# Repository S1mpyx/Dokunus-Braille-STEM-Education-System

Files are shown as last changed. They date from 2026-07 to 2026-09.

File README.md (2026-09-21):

# 📚 Dokunuş – Dijital İnteraktif Kabartma Yazı Eğitim Seti

> **TEKNOFEST 2026 Projesi**  
> **Synapse Takımı**

---

# 👋 Synapse Takımı Hakkında

Merhaba!

Biz **Synapse Takımı** olarak teknolojiyi toplumsal faydaya dönüştürmeyi hedefleyen bir öğrenci ekibiyiz.

Bu proje, görme engelli bireylerin Braille (Kabartma Yazı) eğitimini daha erişilebilir, bağımsız ve ekonomik hale getirmek amacıyla geliştirilmiştir.

Elektronik, yazılım ve üç boyutlu tasarım alanlarını bir araya getirerek öğrencilerin öğretmen veya veli desteğine daha az ihtiyaç duyacağı, sesli geri bildirim sağlayan interaktif bir eğitim sistemi tasarladık.

Amacımız yalnızca bir prototip geliştirmek değil; eğitimde fırsat eşitliğine katkı sağlayabilecek, geliştirilebilir ve ticarileştirilebilir yerli bir ürün ortaya koymaktır.

---

# 👥 Takımımız

## 👨‍💻 Yiğit Dağlı

- Elektronik sistem tasarımı
- Arduino programlama
- Devre kurulumu
- RFID sisteminin geliştirilmesi
- 3B modelleme (Blender)
- Mekanik tasarım
- Prototip üretimi
- Donanım testleri

---

## 👨‍💻 Alperen Arda

**Takım Kaptanı**

- Literatür araştırması
- Yazılım geliştirme
- Ses kayıtlarının hazırlanması
- SD kart içeriklerinin oluşturulması
- Proje dokümantasyonu
- Sunum hazırlanması

---

## 👩‍🏫 Danışman Öğretmen

**Ceren Gezer**

Proje süreci boyunca teknik, akademik ve organizasyonel konularda ekibimize rehberlik etmiştir.

---

# 📖 Proje Hakkında

Dokunuş, görme engelli öğrencilerin Braille alfabesini ve temel sayıları daha kolay öğrenebilmesi amacıyla geliştirilmiş interaktif bir eğitim setidir.

Mevcut eğitim sürecinde öğrenciler çoğu zaman öğretmen veya aile desteğine ihtiyaç duymaktadır. Ayrıca piyasada bulunan elektronik eğitim cihazlarının büyük bölümü ithal olup oldukça yüksek maliyetlidir.

Dokunuş, öğrencinin yaptığı çalışmayı anında değerlendirerek doğru veya yanlış olduğuna dair sesli geri bildirim verir. Böylece öğrenci istediği zaman kendi başına tekrar yapabilir.

---

# 🎯 Projenin Amacı

- Görme engelli öğrencilerin bağımsız öğrenmesini desteklemek
- Braille eğitimini daha erişilebilir hale getirmek
- Öğretmen ve aile üzerindeki yükü azaltmak
- Yerli ve düşük maliyetli bir eğitim sistemi geliştirmek
- Eğitimde fırsat eşitliğine katkı sağlamak


---

# ❓ Çözülen Problem

Braille öğrenme süreci;

- Yoğun tekrar gerektirir.
- Sürekli eğitmen desteğine ihtiyaç duyabilir.
- Öğrenci yaptığı çalışmanın doğru olup olmadığını anında öğrenemeyebilir.
- Elektronik eğitim cihazları yüksek maliyetlidir.

Dokunuş bu problemlere düşük maliyetli ve taşınabilir bir çözüm sunmaktadır.

---

# ⚙️ Sistem Nasıl Çalışır?

1. Öğrenci çalışma modunu seçer.
2. Braille küplerini RFID okuyucular üzerine yerleştirir.
3. RFID etiketleri algılanır.
4. Arduino doğru dizilimi kontrol eder.
5. DFPlayer Mini üzerinden sesli geri bildirim verilir.
6. Öğrenci doğru cevaba ulaşıncaya kadar çalışmaya devam eder.

---

# 📚 Çalışma Modları

## 🔹 Harf Öğrenme Modu

Küp okutulduğunda;

- Harf okunur.
- O harfle başlayan bir hece söylenir.
- O harfle başlayan bir kelime söylenir.

---

## 🔹 Hece Testi

Sistem rastgele bir hece seçer.

Öğrenci doğru harfleri sıralamaya çalışır.

Yanlış cevaplarda doğru dizilime ulaşılıncaya kadar aynı soru tekrar edilir.

---

## 🔹 Sayı Testi

Sistem rastgele üç basamağa kadar sayı oluşturur.

Öğrenci doğru rakamları sıralar.

Doğru cevap sesli olarak onaylanır.

---

# 🛠️ Kullanılan Donanımlar

- Arduino Uno
- 3 × MFRC522 RFID Modülü
- DFPlayer Mini
- Hoparlör
- Push Button
- NFC/RFID Etiketleri
- AMS1117 Voltaj Regülatörü
- Kondansatörler
- 3B Baskı Parçaları

---

# 💻 Kullanılan Yazılımlar

- Arduino IDE
- C++
- Blender

---

# 🖨️ Prototip

Prototipin;

- Elektronik devresi,
- Mekanik tasarımı,
- Yazılımı,
- Braille küpleri,
- Ana gövdesi

Synapse Takımı tarafından geliştirilmiştir.

---

# 💰 Maliyet

| Ürün | Yaklaşık Maliyet |
|---|---:|
| Dokunuş Prototipi | ≈ 1.400 TL |
| Benzer İthal Ürünler | 30.000 – 60.000 TL |

---

# 🎯 Hedef Kitle

- 6–12 yaş arası görme engelli öğrenciler
- Aileler
- Özel eğitim öğretmenleri
- Kaynaştırma sınıfları
- Rehabilitasyon merkezleri
- Görme engelli dernekleri
- Vakıflar
- Millî Eğitim Bakanlığına bağlı eğitim kurumları

---

# 📈 Ticarileştirme Potansiyeli

Dokunuş;

- Yerli üretime uygundur.
- Modüler yapıya sahiptir.
- Düşük maliyetlidir.
- Kolay tamir edilebilir.
- Seri üretime uygundur.

Gelecekte;

- Mobil uygulama
- Öğrenci takip sistemi
- Öğretmen paneli
- Daha fazla RFID okuyucu desteği
- Yeni eğitim modülleri

eklenmesi planlanmaktadır.

---

# SWOT Analizi

## ✅ Güçlü Yönler

- Yerli üretim
- Düşük maliyet
- Türkçe uyumluluğu
- Modüler tasarım
- Kolay tamir edilebilir yapı
- Taşınabilir sistem

## ⚠️ Zayıf Yönler

- İlk prototipte en fazla üç harfli kelimeler oluşturulabilmektedir.
- Kelime havuzu geliştirilmeye açıktır.

## 🚀 Fırsatlar

- Türkiye'de benzer düşük maliyetli ürün bulunmaması
- Eğitim kurumlarında yaygın kullanılabilme potansiyeli
- Açık kaynak olarak geliştirilebilmesi

## ⚡ Tehditler

- Küçük yaş grubundan kaynaklanan fiziksel darbe riski
- Sıvı teması
- Elektronik bileşen maliyetlerindeki değişimler

---

# 📜 Lisans

Bu proje TEKNOFEST kapsamında eğitim ve araştırma amacıyla geliştirilmiştir.

---

# ❤️ Teşekkür

Bu projeye katkı sağlayan danışman öğretmenimize, takım arkadaşlarımıza ve proje sürecinde destek veren herkese teşekkür ederiz.

---

⭐ **Synapse Takımı**  
**TEKNOFEST 2026**

Русский/Rusça

# 📚 Докунуш — Интерактивный цифровой учебный комплект по шрифту Брайля

> **Проект TEKNOFEST 2026**  
> **Команда Synapse**

---

# 👋 О нашей команде

Здравствуйте!

Мы — команда **Synapse**, объединяющая учеников, которые стремятся применять современные технологии для решения социальных задач.

Проект **«Докунуш»** был разработан с целью сделать обучение шрифту Брайля для слабовидящих и незрячих детей более доступным, самостоятельным и эффективным.

Объединив электронику, программирование и 3D-моделирование, мы создали интерактивную обучающую систему, способную давать голосовую обратную связь и помогать ученикам заниматься без постоянной помощи преподавателя.

Наша цель — не только создать прототип, но и разработать отечественный, доступный и масштабируемый образовательный продукт.

---

# 👥 Команда проекта

## 👨‍💻 Йигит Даглы

- Разработка электронной части проекта
- Программирование Arduino
- Сборка электронных схем
- Разработка RFID-системы
- 3D-моделирование (Blender)
- Механическое проектирование
- Изготовление прототипа
- Тестирование аппаратной части

---

## 👨‍💻 Альперен Арда

**Капитан команды**

- Анализ научной литературы
- Разработка программного обеспечения
- Подготовка аудиоматериалов
- Создание содержимого SD-карты
- Подготовка проектной документации
- Подготовка презентации

---

## 👩‍🏫 Руководитель проекта

**Джерен Гезер**

Оказывала научное и техническое руководство на всех этапах разработки проекта.

---

# 📖 О проекте

**«Докунуш»** — это интерактивный учебный комплект, предназначенный для обучения незрячих детей шрифту Брайля и основам счёта.

Во многих случаях обучение требует постоянного участия преподавателя или родителей. Кроме того, большинство электронных обучающих устройств являются импортными и имеют высокую стоимость.

Разработанная нами система позволяет автоматически проверять ответы ученика и мгновенно сообщать о результате с помощью голосовой обратной связи.

Таким образом ученик может самостоятельно выполнять упражнения и закреплять материал.

---

# 🎯 Цель проекта

Проект направлен на:

- развитие самостоятельного обучения;
- облегчение изучения шрифта Брайля;
- поддержку инклюзивного образования;
- снижение зависимости от преподавателя;
- создание доступной отечественной образовательной системы.


---

# ❓ Решаемая проблема

При изучении шрифта Брайля учащиеся сталкиваются со следующими трудностями:

- необходимость постоянной помощи преподавателя;
- отсутствие мгновенной проверки правильности ответа;
- высокая стоимость существующих электронных устройств.

Проект «Докунуш» предлагает доступное и мобильное решение этих проблем.

---

# ⚙️ Принцип работы

1. Пользователь выбирает режим обучения.
2. Кубики Брайля размещаются на RFID-считывателях.
3. RFID-метки распознаются системой.
4. Arduino анализирует правильность ответа.
5. DFPlayer Mini воспроизводит голосовую обратную связь.
6. Ученик продолжает обучение до получения правильного результата.

---

# 📚 Режимы работы

## 🔹 Изучение букв

После считывания кубика система произносит:

- букву;
- слог;
- слово, начинающееся с данной буквы.

---

## 🔹 Проверка слогов

Система случайным образом выбирает слог.

Ученик составляет его с помощью кубиков.

При неправильном ответе вопрос повторяется до правильного выполнения.

---

## 🔹 Проверка чисел

Система случайным образом озвучивает числа до трёх разрядов.

Ученик должен составить правильную последовательность цифр.

---

# 🛠 Используемое оборудование

- Arduino Uno
- 3 модуля RFID MFRC522
- DFPlayer Mini
- Динамик
- Кнопки управления
- RFID/NFC-метки
- Стабилизатор напряжения AMS1117
- Конденсаторы
- Детали, изготовленные на 3D-принтере

---

# 💻 Используемое программное обеспечение

- Arduino IDE
- C++
- Blender

---

# 🖨 Прототип

Командой Synapse были самостоятельно разработаны:

- электронная схема;
- программное обеспечение;
- корпус устройства;
- кубики Брайля;
- механическая конструкция.

---

# 💰 Стоимость

| Наименование | Стоимость |
|---|---:|
| Прототип «Докунуш» | ≈ 1400 турецких лир |
| Импортные аналоги | 30 000–60 000 турецких лир |

---

# 🎯 Целевая аудитория

- незрячие дети 6–12 лет;
- родители;
- учителя специального образования;
- инклюзивные классы;
- реабилитационные центры;
- школы;
- общественные организации и фонды.

---

# 📈 Потенциал коммерциализации

Проект обладает следующими преимуществами:

- отечественная разработка;
- модульная конструкция;
- низкая стоимость производства;
- простота ремонта;
- возможность серийного производства.

В дальнейшем планируется добавить:

- мобильное приложение;
- систему отслеживания успеваемости;
- панель преподавателя;
- поддержку большего количества RFID-считывателей;
- новые образовательные режимы.

---

# SWOT-анализ

## ✅ Сильные стороны

- отечественная разработка;
- низкая стоимость;
- поддержка турецкого языка;
- модульная конструкция;
- ремонтопригодность;
- портативность.

## ⚠️ Слабые стороны

- текущий прототип поддерживает слова длиной до трёх букв;
- словарный запас может быть расширен.

## 🚀 Возможности

- отсутствие аналогичных доступных решений в Турции;
- высокий потенциал внедрения в образовательные учреждения;
- возможность развития проекта как открытого программного обеспечения.

## ⚡ Угрозы

- механические повреждения при использовании детьми;
- воздействие влаги;
- изменение стоимости электронных компонентов.

---

# 📜 Лицензия

Проект разработан исключительно в образовательных и исследовательских целях в рамках конкурса **TEKNOFEST 2026**.

---

# ❤️ Благодарности

Выражаем искреннюю благодарность нашему научному руководителю, всем членам команды и каждому, кто поддержал нас в процессе разработки проекта.

---

⭐ **Команда Synapse**  
**TEKNOFEST 2026**

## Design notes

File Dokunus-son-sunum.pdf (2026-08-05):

# İNSANLIK YARARINA TEKNOLOJİLER YARIŞMASI

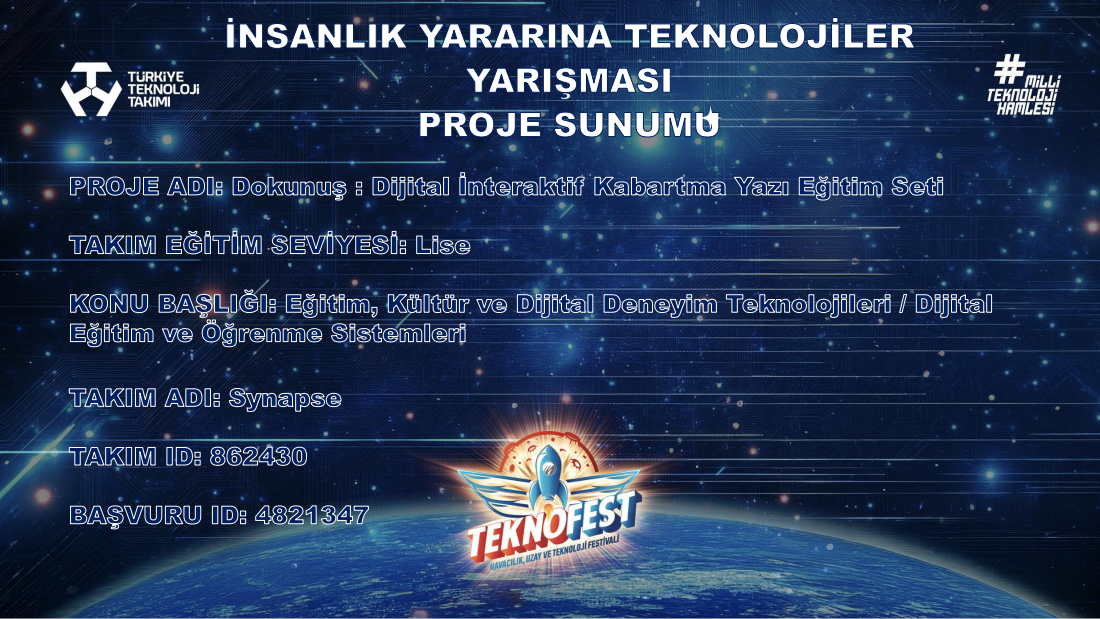
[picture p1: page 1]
PROJE SUNUMU; TAKIM ID: 862430; BAŞVURU ID: 4821347

PROJE ADI: Dokunuş : Dijital İnteraktif Kabartma Yazı Eğitim Seti

TAKIM EĞİTİM SEVİYESİ: Lise

KONU BAŞLIĞI: Eğitim, Kültür ve Dijital Deneyim Teknolojileri / Dijital
Eğitim ve Öğrenme Sistemleri

TAKIM ADI: Synapse

### TAKIM YAPISI

DEVRE KURULUMU
3D TASARIM

YİĞİT DAĞLI

# PROJE TAKIMI VE GÖREV PAYLAŞIMI

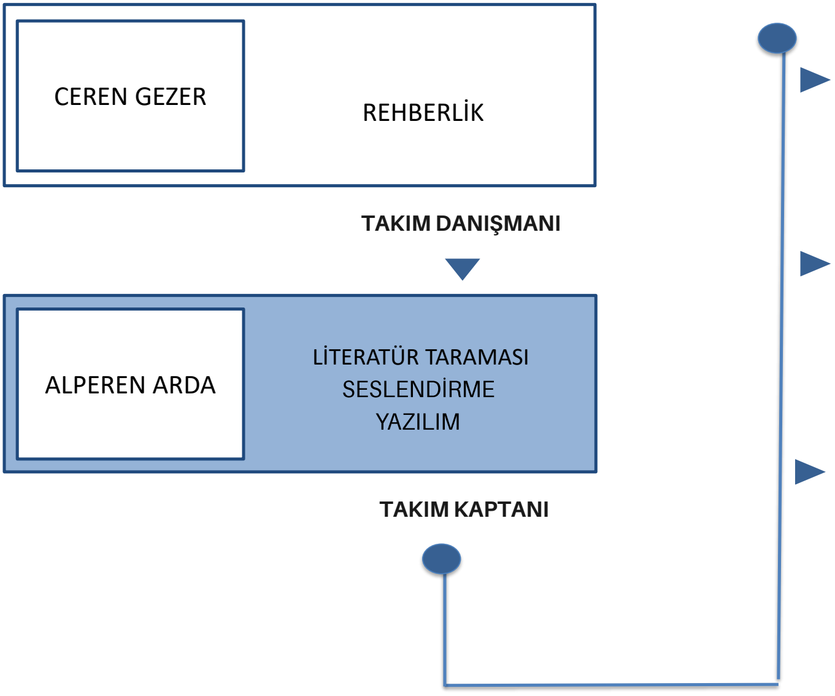
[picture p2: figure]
TAKIM DANIŞMANI; TAKIM KAPTANI; REHBERLİK; LİTERATÜR TARAMASI SESLENDİRME YAZILIM; CEREN GEZER; ALPEREN ARDA

2026 TEKNOFEST İNSANLIK YARARINA TEKNOLOJİLER YARIŞMASI LİSE SEVİYESİ PROJE SUNUMU

ÜYE

Synapse
862430
4821347

# PROJE ÖZETİ VE KAPSAMI

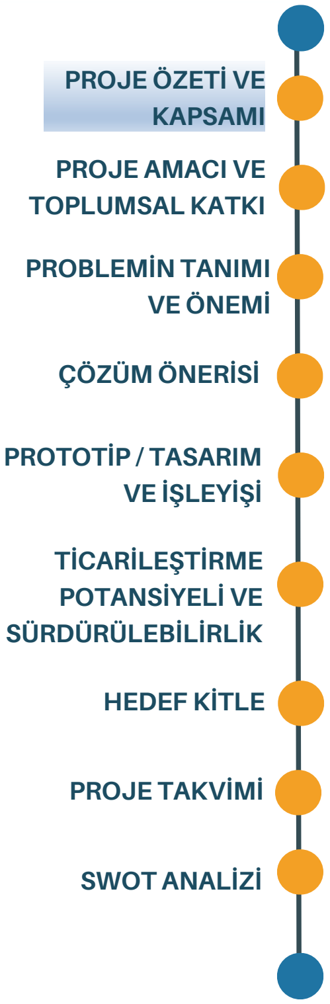
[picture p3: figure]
PROTOTİP / TASARIM VE İŞLEYİŞİ; ÇÖZÜM ÖNERİSİ; SWOT ANALİZİ; TİCARİLEŞTİRME POTANSİYELİ VE SÜRDÜRÜLEBİLİRLİK; PROJE TAKVİMİ; PROJE AMACI VE TOPLUMSAL KATKI; PROBLEMİN TANIMI VE ÖNEMİ; PROJE ÖZETİ VE; KAPSAMI; HEDEF KİTLE

# - Proje Adı : Dokunuş: Dijital İnteraktif Kabartma Yazı Eğitim Seti

- Ana Fikir / Problem : Görme engelli bireylerin Braille alfabesi ve sayı okunuşu öğreniminde sürekli bir eğitmene bağımlı olmaları ve mevcut sesli/interaktif eğitim cihazlarının yüksek maliyetleri nedeniyle
- | Çözüm Yaklaşımı : Bireysel ve bağımsız öğrenmeyi destekleyecek bir eğitim materyali | gelişirmek . 3D yazıcı
ile üretilen, içerisinde RFID etiketler bulunan kabartma küpler ve 3 yuvalı Arduino tabanlı bir ana ünite
tasarlanmıştır. Sistem, «Öğrenme Modu» ile harfleri ve rakamları tanımayı sağlar. «Hece Test Modu»
(hece/harf okuma ve yazma) ve «Sayı Test Modu»(3 basamağa kadar olan rakam ve sayıların yazımı) ile de
| etkileşimli bir kendi kendini değerlendirme imkanı sunar.
- Beklenen Etki : Görme engelli öğrencilerin dokunsal ve işitsel dönütlerle, eğitmen yardımı olmadan müsait her ortamda eğitimlerine devam edebilmeleri beklenmektedir. Deneme -yanılma yoluyla etkileşimli şekilde, okuma -yazma ve sayıları öğrenmelerini sağlamaktır. Mobil bir kit olduğu için kolay taşınabilir, ucuz maliyetiyle benzerlerine oranla daha ulaşılabilir olması hedeflenmiştir. Ayrıca yerli olması sebebiyle Türkçe karakterlerle tam uyumludur. Maarif model okuma yazma eğitimine uyumlu hazırlanarak engelsiz akranları ile de eğitimde
| birlik yakalanmak istenmiştir.
- Ana / Alt Tema Uyumu : Eğitim, Kültür ve Dijital Deneyim Teknolojileri / Dijital Eğitim ve Öğrenme Sistemleri ile tam uyumludur. Projemiz engellilere yönelik elektronik etkileşimli bir dijital eğitim ve öğrenme

Synapse

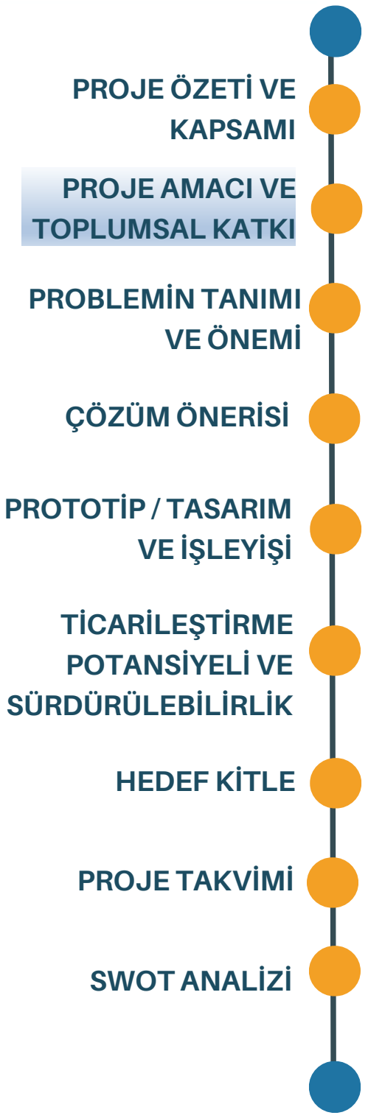
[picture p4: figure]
PROTOTİP / TASARIM VE İŞLEYİŞİ; ÇÖZÜM ÖNERİSİ; SWOT ANALİZİ; TİCARİLEŞTİRME POTANSİYELİ VE SÜRDÜRÜLEBİLİRLİK; PROJE TAKVİMİ; PROJE AMACI VE TOPLUMSAL KATKI; PROBLEMİN TANIMI VE ÖNEMİ; PROJE ÖZETİ VE; KAPSAMI; HEDEF KİTLE
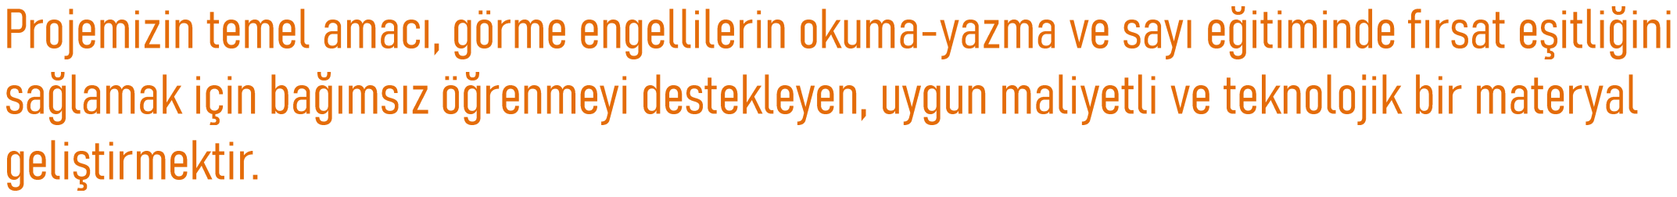
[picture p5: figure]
geliştirmektir.

Projemizin temel amacı, görme engellilerin okuma -yazma ve sayı eğitiminde fırsat eşitliğini

## sağlamak için bağımsız öğrenmeyi destekleyen, uygun maliyetli ve teknolojik bir materyal

Toplumsal Katkısı: Geleneksel çivi ve tablet yada kitaptan kabartma harf okutma yöntemiyle
öğrenmek küçük yaşlardaki çocuklar için hem sıkıcı hem de bir eğitmene bağımlı kılan öğrenme sistemleridir. Bizim geliştirdiğimiz sistem ile görme engelli bireyler eğitmenden bağımsız kabartama yazı ve sayı okuma / yazma pratiği yapabileceklerdir. Bu da öğrenme hızlarını artıracak ve onlara bu aşamada yardımcı olan ebeveynlerin ve öğretmenlerin yükünü hafifletecektir.

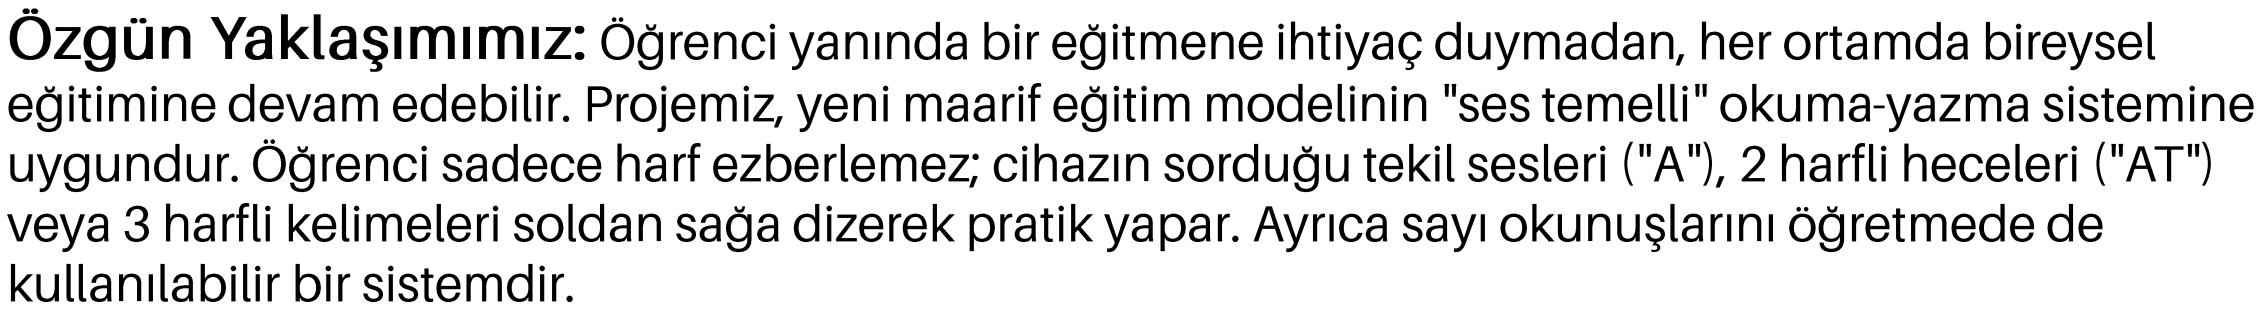
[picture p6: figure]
kullanılabilir bir sistemdir.

Özgün Yaklaşımımız: | Öğrenci yanında bir eğitmene ihtiyaç duymadan, her ortamda bireysel
eğitimine devam edebilir. Projemiz, yeni maarif eğitim modelinin "ses temelli" okuma | -yazma sistemine
uygundur. Öğrenci sadece harf ezberlemez; cihazın sorduğu tekil sesleri ("A"), 2 harfli heceleri ("AT")
veya 3 harfli kelimeleri soldan sağa dizerek pratik yapar. Ayrıca sayı okunuşlarını öğretmede de

# PROJE AMACI VE TOPLUMSAL KATKI

LİSE SEVİYESİ PROJE SUNUM ŞABLONU

Synapse

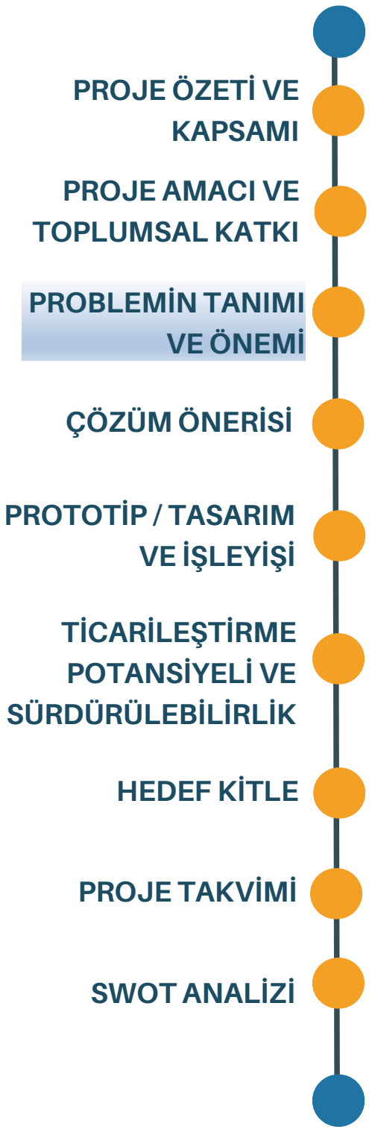
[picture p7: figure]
PROTOTİP / TASARIM VE İŞLEYİŞİ; ÇÖZÜM ÖNERİSİ; SWOT ANALİZİ; TİCARİLEŞTİRME POTANSİYELİ VE SÜRDÜRÜLEBİLİRLİK; PROJE TAKVİMİ; PROJE AMACI VE TOPLUMSAL KATKI; PROBLEMİN TANIMI VE ÖNEMİ; PROJE ÖZETİ VE; KAPSAMI; HEDEF KİTLE
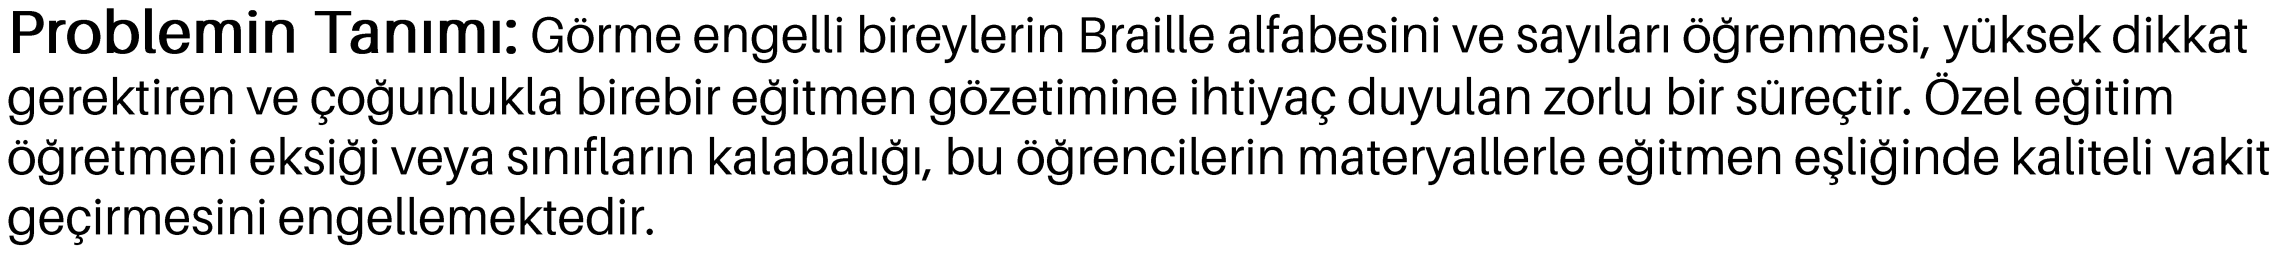
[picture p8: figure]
geçirmesini engellemektedir.

Problemin Tanımı: Görme engelli bireylerin Braille alfabesini ve sayıları öğrenmesi, yüksek dikkat gerektiren ve çoğunlukla birebir eğitmen gözetimine ihtiyaç duyulan zorlu bir süreçtir. Özel eğitim
öğretmeni eksiği veya sınıfların kalabalığı, bu öğrencilerin materyallerle eğitmen eşliğinde kaliteli vakit

Problemin Etkileri: Birebir eğitim alacağı eğitmenle sınırlı zaman geçirmesi , öğrencinin anında dönüt alamaması (yazdığı harfin doğru olup olmadığını anında duyamaması) öğrenme sürecini uzatır, yanlış öğrenmeleri kalıcı hale getirir ve bireyin özgüvenini düşürür.

Mevcut Çözümler ve Eksikleri: Literatür ve pazar araştırmalarımızda elektronik Braille eğitim setlerinin ( Örn: Taptilo vb. ithal markalar) var olduğu görülmüştür. Ancak bu ürünler 30.000 TL ile 60.000 TL bandında ithal çözümlerdir. Türk harf/ses yapısına tam uyumlu olmamakla birlikte, fiyatları sebebiyle devlet okulları, dernekler veya dar gelirli aileler için erişilebilir değildir.
Literatürde yer alan OntoBraille@RFID (Tang , 2013) çalışması, Braille eğitiminde RFID kullanımının teorik altyapısını başarıyla oluşturmuştur. Ancak sadece İngilizce ve Çince Braille öğretimi için uygundur. Ticarileşememiş, akademik bir çalışmayla sınırlı kalmıştır.
LEGO Braille Bricks ve Tack -Tiles adıyla piyasada satılan kabartma lego setler vardır ancak etkileşimsiz, eğitici onayına ihtiyaç duyan materyallerdir.
Ayrıca çözümlerin tamamı Barille okuma öğretimi üzerinde çözümler üretmektedir. Sayı okunuşu pratiği yapma konusunda bir çözüm sunmamaktadırlar.

# PROBLEMİN TANIMI VE ÖNEMİ

Synapse

Çözüm: Braille harfleri ve sayıları barındıran akıllı küplerin, okuyucu yuvalara yerleştirilmesiyle sesli tepki

### Çalışma Mantığı:

Mod 1 (Öğrenme): Yuvaya konan harfin veya rakamın sesi anında cihazdan ( DFPlayer ) duyulur. (Sadece sol yuva aktif)
Mod 2 (Hece/Kelime Test): Cihaz önceden tanımlı listeden rastgele bir ses ("A"), 2 harfli hece ("AL") veya 3 harfli kelime ("ALİ") söyler. Öğrenci soldan sağa doğru küpleri dizer ve "Onay" butonuna basar. Doğruysa "Tebrikler", yanlışsa "Tekrar Dene" sesi çalar.
Mod 3 (Sayı Test): 1, 2 veya 3 basamaklı sayılar rastgele sorulur, kullanıcı dizer ve test edilir.
Pedagojik Kural: Öğrenme modunda birkaç yuvada eş zamanlı küp olması karmaşaya yol açacağı için sadece en soldaki RFID okuyucu anlık ses verir, diğer okuyucular sessizdir.
Test modlarında ise dizilim bittikten sonra onay tuşuna basması beklenir. Bu da süre sınırı olmadan öğrencinin kendi hızında çalışmasına zemin hazırlar.

Bu şekilde görme engelli bireyler zamandan, mekandan ve eğitmenden bağımsız bir şekilde okuma, yazma, sayı

Günlük Hayatta Kullanımı: Görme engelliler okulundaki bir öğrenci, derste öğrendiği harfleri evinde tek başına pekiştirmek için bu kiti kullanabilir. Yada okullarda doğrudan bu kit ile pratik yapmasına olanak veren ders planlamaları oluşturulabilir. Örneğin, bir eğitmen sınıfta bir öğrenci ile birebir ilgilenirken diğerleri de bu süreyi bu kit ile bireysel öğrenme şeklinde değerlendirebilir.

# ÇÖZÜM ÖNERİSİ

PROTOTİP / TASARIM
VE İŞLEYİŞİ

ÇÖZÜM ÖNERİSİ

SWOT ANALİZİ

TİCARİLEŞTİRME
POTANSİYELİ VE
SÜRDÜRÜLEBİLİRLİK

PROJE TAKVİMİ

PROJE AMACI VE
TOPLUMSAL KATKI

PROBLEMİN TANIMI
VE ÖNEMİ

PROJE ÖZETİ VE
KAPSAMI

HEDEF KİTLE

Synapse

# ÇÖZÜM ÖNERİSİ

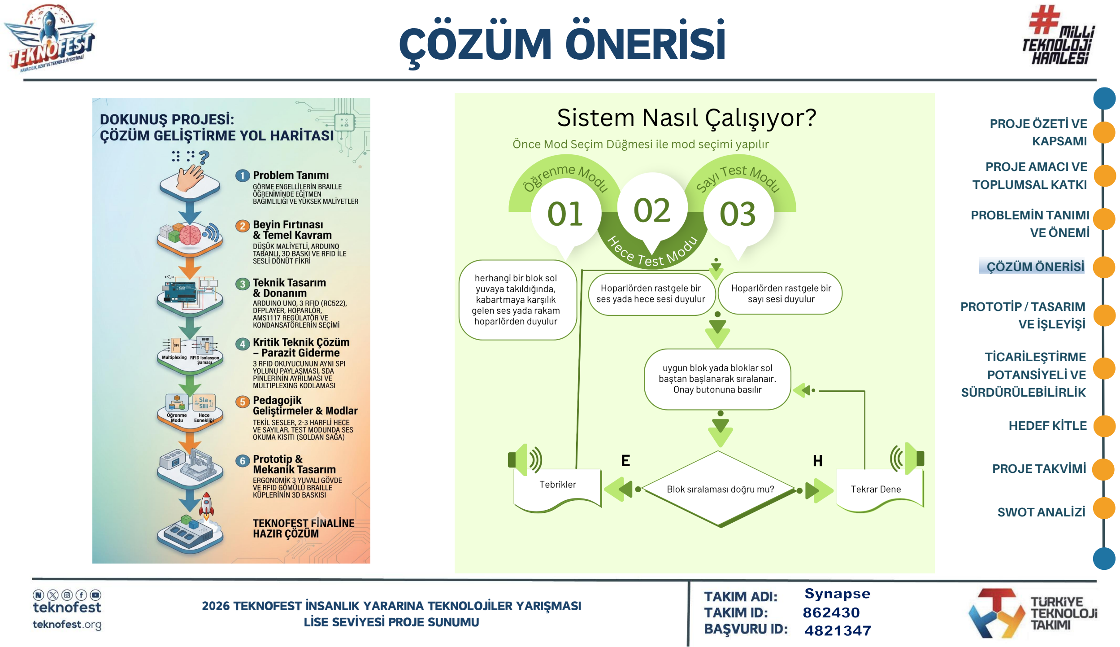
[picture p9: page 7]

PROTOTİP / TASARIM
VE İŞLEYİŞİ

ÇÖZÜM ÖNERİSİ

SWOT ANALİZİ

TİCARİLEŞTİRME
POTANSİYELİ VE
SÜRDÜRÜLEBİLİRLİK

PROJE TAKVİMİ

PROJE AMACI VE
TOPLUMSAL KATKI

PROBLEMİN TANIMI
VE ÖNEMİ

PROJE ÖZETİ VE
KAPSAMI

HEDEF KİTLE

Synapse

# PROTOTİP / TASARIM VE İŞLEYİŞİ

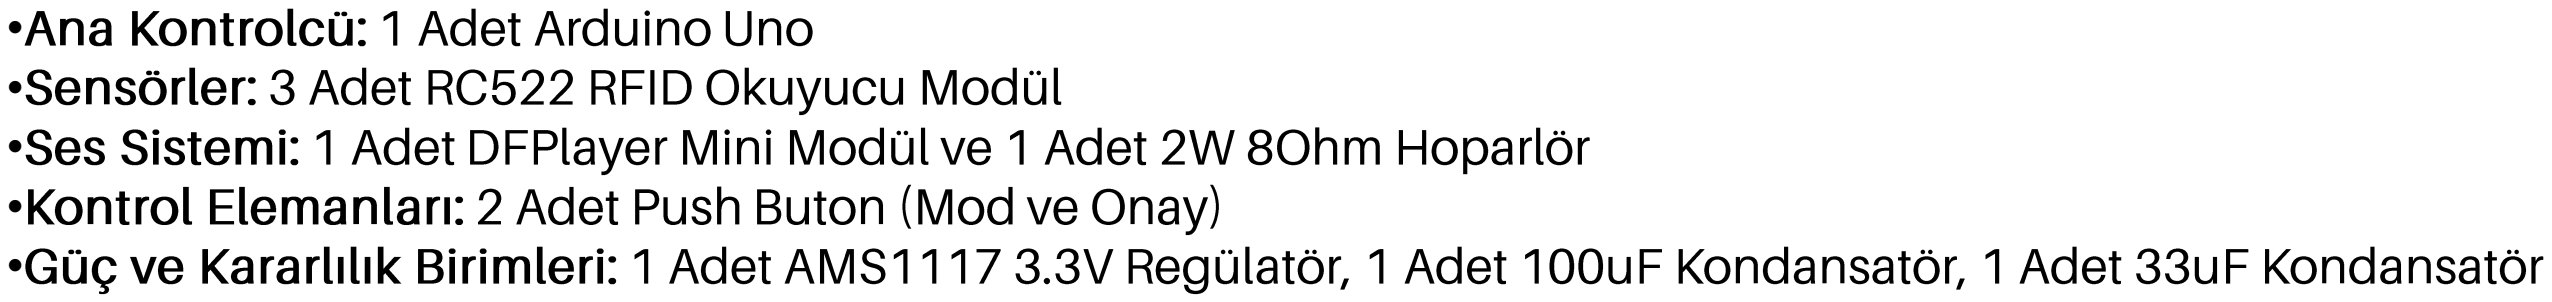
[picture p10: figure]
•Ana Kontrolcü: 1 Adet Arduino Uno

PROTOTİP / TASARIM
VE İŞLEYİŞİ

ÇÖZÜM ÖNERİSİ

SWOT ANALİZİ

TİCARİLEŞTİRME
POTANSİYELİ VE
SÜRDÜRÜLEBİLİRLİK

PROJE TAKVİMİ

PROJE AMACI VE
TOPLUMSAL KATKI

PROBLEMİN TANIMI
VE ÖNEMİ

PROJE ÖZETİ VE
KAPSAMI

HEDEF KİTLE

Synapse

Projemiz donanım, yazılım ve 3D mekanik tasarımın birleştiği hibrit bir sistemdir.

Kullanılan Devre Elemanları:

•Sensörler: 3 Adet RC522 RFID Okuyucu Modül
•Ses Sistemi: 1 Adet DFPlayer Mini Modül ve 1 Adet 2W 8Ohm Hoparlör
•Kontrol Elemanları: 2 Adet Push Buton (Mod ve Onay)
•Güç ve Kararlılık Birimleri: 1 Adet AMS1117 3.3V Regülatör, 1 Adet 100uF Kondansatör, 1 Adet 33uF Kondansatör Yazılım ve Donanım İşleyişi :
•Güç Yönetimi: 3 adet RFID okuyucunun Arduino | Uno üzerinden güç çekerken oluşturabileceği akım yetersizliğini
ve resetlenme sorunlarını önlemek adına | AMS1117 3.3V voltaj regülatörü | kullanılmıştır. Elektriksel gürültüyü
(dalgalanmaları) filtrelemek ve sistemi kararlı kılmak için devreye | 100uF ve 33uF kondansatörler | entegre edilmiştir.
•Multiplexing (Çoklama) Metodu: RFID okuyucular yan yana konduğunda elektromanyetik parazit ( | Interference )
oluşur. Bunu çözmek için okuyucuların SPI protokolündeki | SDA (SS) pinleri ayrı dijital pinlere bağlanmıştır.
Yazılımda aynı anda sadece 1 okuyucu aktif edilir (milisaniyeler içinde), okuma yapılır ve kapatılıp diğerine geçilir.

•Mekanik İzolasyon: 3D tasarımda yuvalar arasındaki et kalınlığı, okuyucu antenlerin manyetik çakışmasını fiziksel olarak engelleyecek optimum mesafede hesaplanmıştır.

# PROTOTİP / TASARIM VE İŞLEYİŞİ

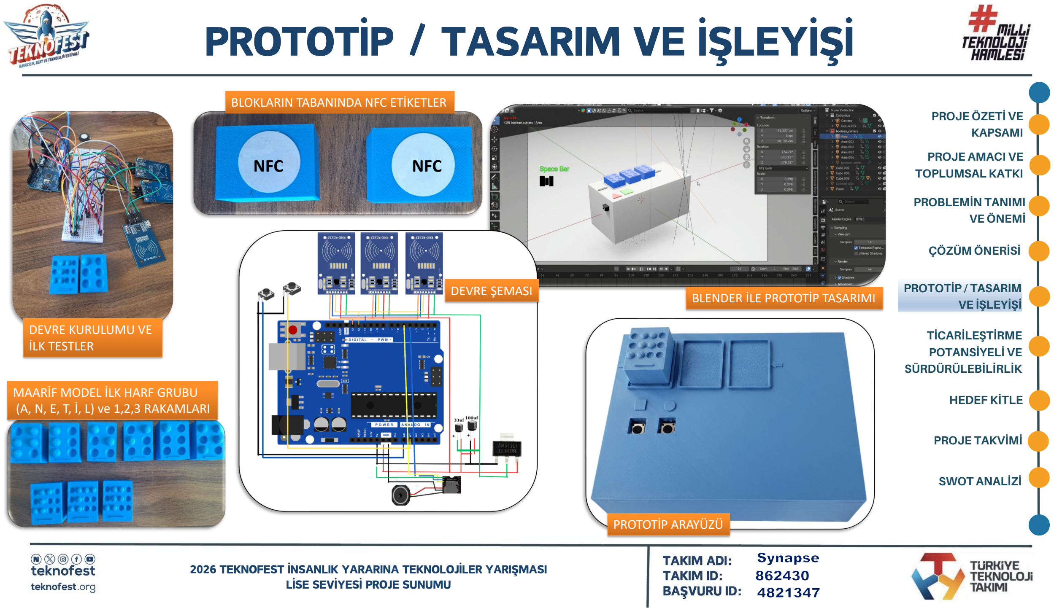
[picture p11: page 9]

PROTOTİP / TASARIM
VE İŞLEYİŞİ

ÇÖZÜM ÖNERİSİ

SWOT ANALİZİ

TİCARİLEŞTİRME
POTANSİYELİ VE
SÜRDÜRÜLEBİLİRLİK

PROJE TAKVİMİ

PROJE AMACI VE
TOPLUMSAL KATKI

PROBLEMİN TANIMI
VE ÖNEMİ

PROJE ÖZETİ VE
KAPSAMI

HEDEF KİTLE

Synapse

NFC | NFC

BLENDER İLE PROTOTİP TASARIMI

BLOKLARIN TABANINDA NFC ETİKETLER

DEVRE KURULUMU VE
İLK TESTLER

DEVRE ŞEMASI

MAARİF MODEL İLK HARF GRUBU (A, N, E, T, İ, L) ve 1,2,3 RAKAMLARI

PROTOTİP ARAYÜZÜ

### Ticarileşme Potansiyeli:

Projemiz, yerli ve milli bir eğitim teknolojisi olarak çok yüksek bir ticari avantaja sahiptir. Piyasada 30.000 TL üzeri satılan ithal kitlere karşı, "Dokunuş" setinin toplam malzeme donanım maliyeti yaklaşık 1000 TL, 3D baskı (PLA Filament -sistem için yaklaşık 700 gram) maliyeti ise ortalama 400 TL'dir. Toplamda 1400 TL gibi çok uygun bir bütçeyle üretilebilmektedir. Görme engelli çocuğu olan ebeveynler, MEB Özel Eğitim Genel Müdürlüğü, Görme Engelliler Dernekleri ve vakıflar potansiyel alıcılardır (B2G ve B2B pazar yapısı).

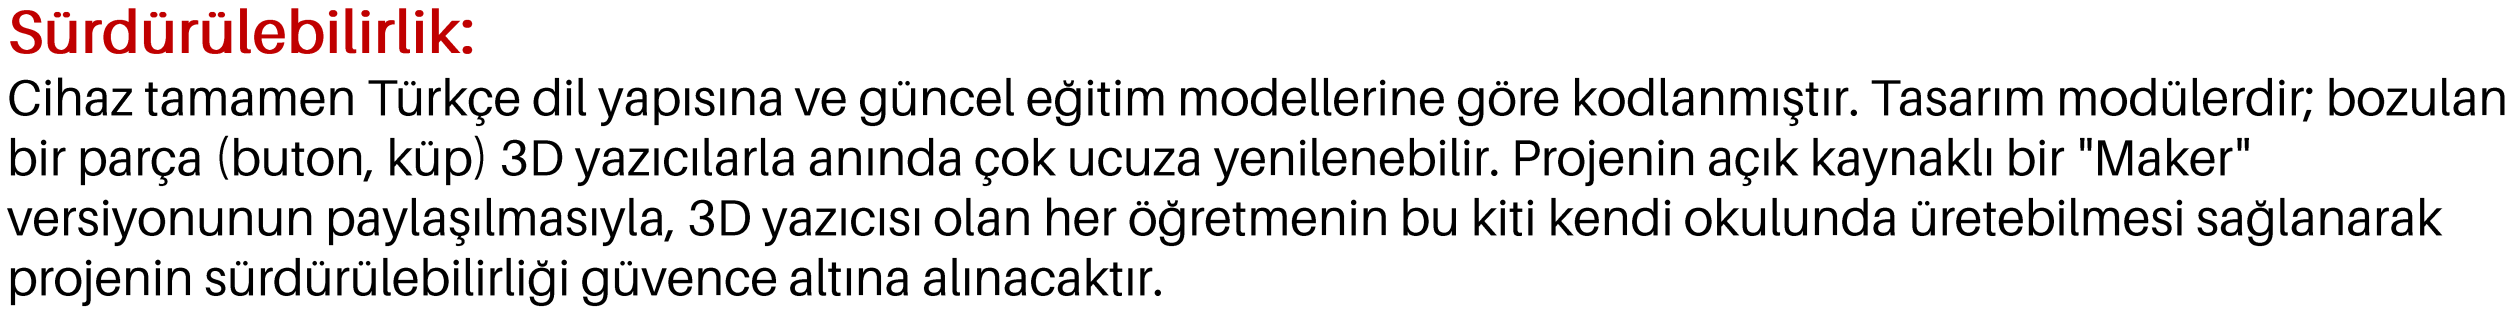
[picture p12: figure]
Sürdürülebilirlik:

Cihaz tamamen Türkçe dil yapısına ve güncel eğitim modellerine göre kodlanmıştır. Tasarım modülerdir; bozulan bir parça (buton, küp) 3D yazıcılarla anında çok ucuza yenilenebilir. Projenin açık kaynaklı bir "Maker" versiyonunun paylaşılmasıyla, 3D yazıcısı olan her öğretmenin bu kiti kendi okulunda üretebilmesi sağlanarak projenin sürdürülebilirliği güvence altına alınacaktır.

# TİCARİLEŞME POTANSİYELİ VE SÜRDÜRÜLEBİLİRLİK

PROTOTİP / TASARIM
VE İŞLEYİŞİ

ÇÖZÜM ÖNERİSİ

SWOT ANALİZİ

TİCARİLEŞTİRME
POTANSİYELİ VE
SÜRDÜRÜLEBİLİRLİK

PROJE TAKVİMİ

PROJE AMACI VE
TOPLUMSAL KATKI

PROBLEMİN TANIMI
VE ÖNEMİ

PROJE ÖZETİ VE
KAPSAMI

HEDEF KİTLE

Synapse

# HEDEF KİTLE

PROTOTİP / TASARIM
VE İŞLEYİŞİ

ÇÖZÜM ÖNERİSİ

SWOT ANALİZİ

TİCARİLEŞTİRME
POTANSİYELİ VE
SÜRDÜRÜLEBİLİRLİK

PROJE TAKVİMİ

PROJE AMACI VE
TOPLUMSAL KATKI

PROBLEMİN TANIMI
VE ÖNEMİ

PROJE ÖZETİ VE
KAPSAMI

HEDEF KİTLE

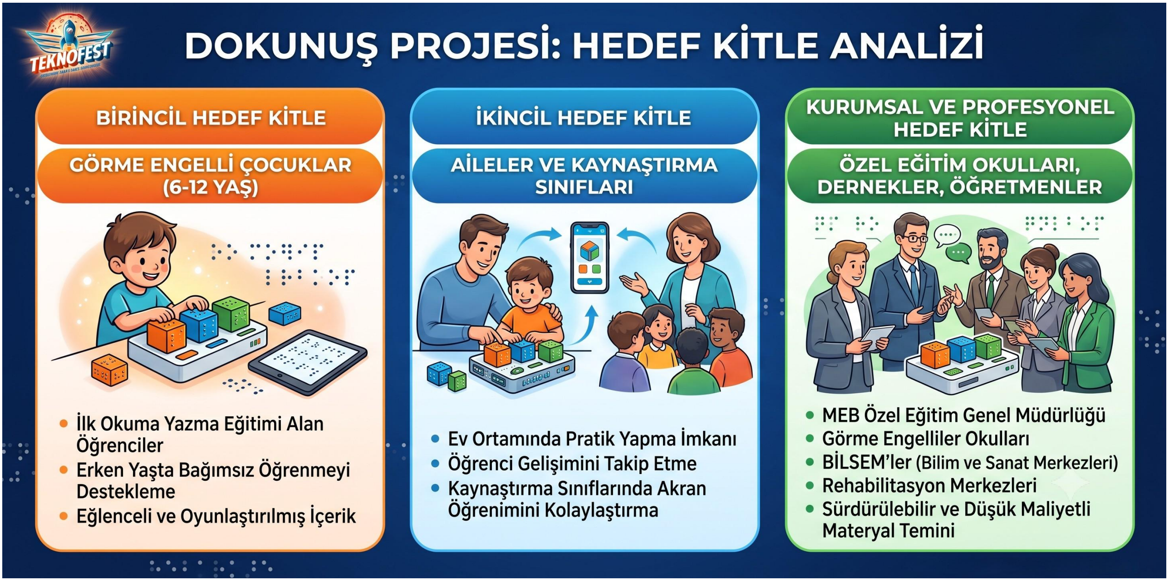
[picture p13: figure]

Synapse

# PROJE TAKVİMİ

İş Paketi No | İŞ PAKETİ ADI | ALT FAALİYETLER | BAŞLANGIÇ TARİHİ | BİTİŞ TARİHİ
1 | Araştırma ve Literatür Taraması | Engelli marketleri incelenmesi | 1.03.2026 | 5.03.2026
2 | Araştırma ve Literatür Taraması | Benzer akademik çalışmaların araştırılması | 5.03.2026 | 10.03.2026
3 | Araştırma ve Literatür Taraması | Görme engelli okul sitelerinin incelenmesi , harf ve sayıların kabartma gösterimleri | 11.03.2026 | 12.03.2026
4 | Donanımın Belirlenmesi ve Temini | İhtiyaç listesi oluşturma | 15.03.2026 | 20.03.2026
5 | Donanımın Belirlenmesi ve Temini | Sipariş ve sağlamlık testleri | 21.03.2026 | 30.03.2026
6 | Devre kurulumu ve Kodlama | Devre kurulumu | 01.04.2026 | 15.04.2026
7 | Devre kurulumu ve Kodlama | Yazılım ve Test | 15.04.2026 | 30.04.2026
8 | 3D Tasarım ve Baskı | Blender Programı ile küplerin ve prototipin tasarlanması | 01.05.2026 | 10.05.2026
9 | 3D Tasarım ve Baskı | Yazıcıdan baskı alma | 10.05.2026 | 14.05.2026
10 | Sistem Entegrasyonu | Seslerin kaydedilmesi ve sd karta yüklenmesi | 01.05.2026 | 10.05.2026
11 | Sistem Entegrasyonu | Algoritma optimizasyonu , hata yakalama ve düzeltme | 11.05.2026 | 29.05.2026
12 | Montaj | Nihai montaj | 29.05.2026 | 06.06.2026
13 | Raporlama | Proje detay raporunun ve sunumunun hazırlanması | 07.06.2026 | 28.06.2026

PROTOTİP / TASARIM
VE İŞLEYİŞİ

ÇÖZÜM ÖNERİSİ

SWOT ANALİZİ

TİCARİLEŞTİRME
POTANSİYELİ VE
SÜRDÜRÜLEBİLİRLİK

PROJE TAKVİMİ

PROJE AMACI VE
TOPLUMSAL KATKI

PROBLEMİN TANIMI
VE ÖNEMİ

PROJE ÖZETİ VE
KAPSAMI

HEDEF KİTLE

Synapse

# SWOT ANALİZİ

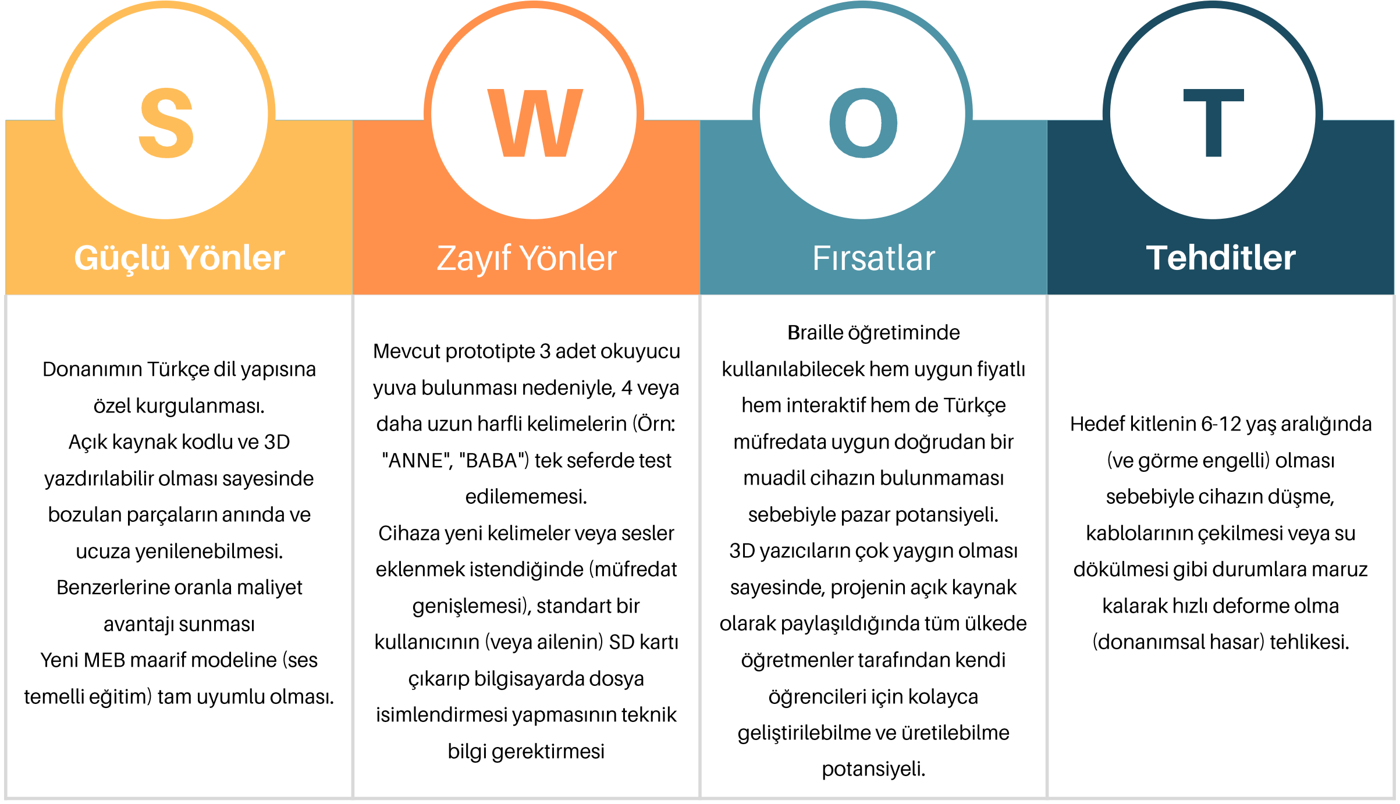
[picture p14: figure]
Donanımın Türkçe dil yapısına; özel kurgulanması.; Açık kaynak kodlu ve 3D; yazdırılabilir olması sayesinde; bozulan parçaların anında ve; ucuza yenilenebilmesi.; Benzerlerine oranla maliyet; avantajı sunması; Yeni MEB maarif modeline (ses; temelli eğitim) tam uyumlu olması.; Mevcut prototipte 3 adet okuyucu; yuva bulunması nedeniyle, 4 veya; daha uzun harfli kelimelerin ( Örn:; "ANNE", "BABA") tek seferde test; edilememesi.; Cihaza yeni kelimeler veya sesler; eklenmek istendiğinde (müfredat; genişlemesi), standart bir; kullanıcının (veya ailenin) SD kartı; çıkarıp bilgisayarda dosya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

Güçlü Yönler | Zayıf Yönler | Fırsatlar | Tehditler

PROTOTİP / TASARIM
VE İŞLEYİŞİ

ÇÖZÜM ÖNERİSİ

SWOT ANALİZİ

TİCARİLEŞTİRME
POTANSİYELİ VE
SÜRDÜRÜLEBİLİRLİK

PROJE TAKVİMİ

PROJE AMACI VE
TOPLUMSAL KATKI

PROBLEMİN TANIMI
VE ÖNEMİ

PROJE ÖZETİ VE
KAPSAMI

HEDEF KİTLE

Synapse

# TEŞEKKÜRLER

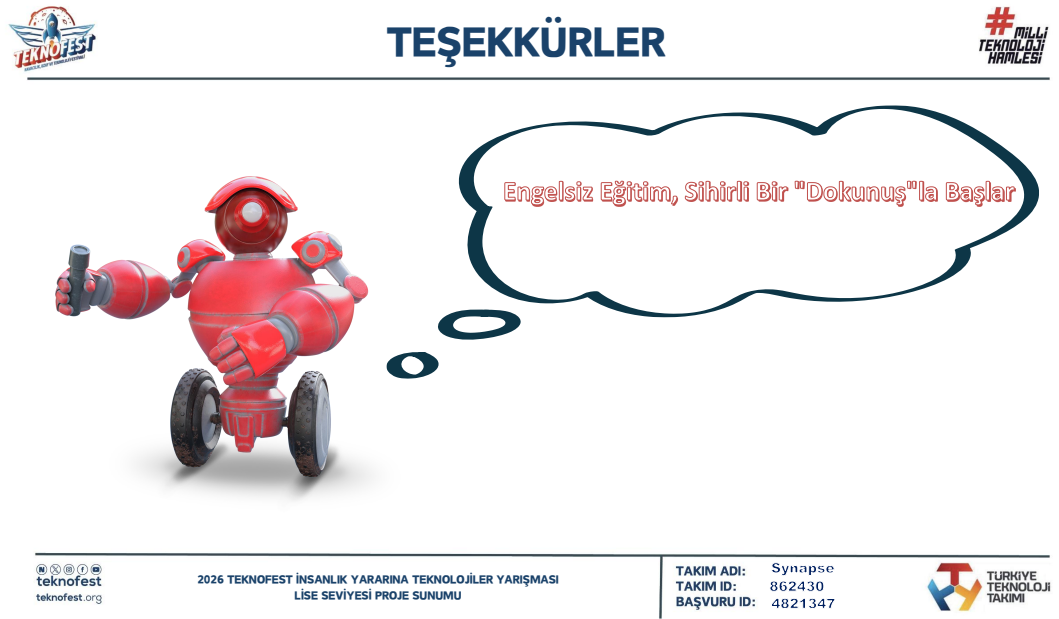
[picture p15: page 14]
Synapse

Engelsiz Eğitim, Sihirli Bir "Dokunuş"la Başlar

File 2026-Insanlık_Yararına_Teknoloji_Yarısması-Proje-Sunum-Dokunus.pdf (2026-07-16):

# İNSANLIK YARARINA

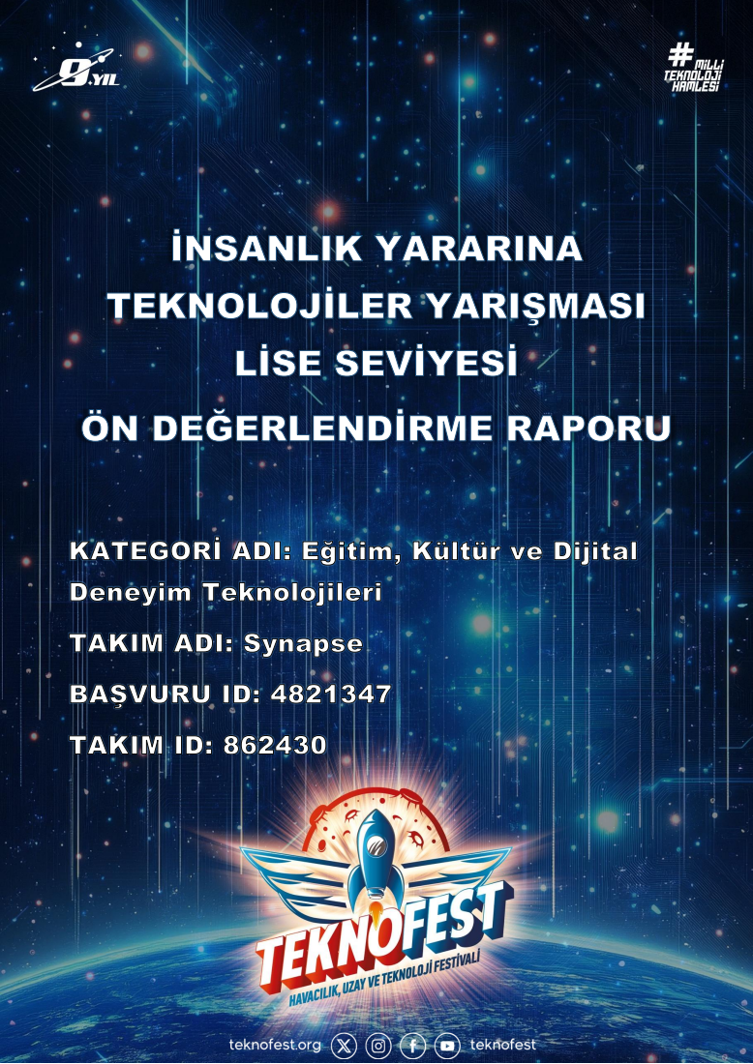
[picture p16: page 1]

İÇİNDEKİLER

### 1. PROJE ÖZETİ

### 1.1. Proje Özeti ve Proje Kapsamı

"Dokunuş: Dijital İnteraktif Kabartma Yazı Eğitim Seti" adlı projemizin temel amacı, görme engelli çocukların Braille alfabesini öğrenirken sürekli eğitmen ihtiyacı duymalarını ortadan kaldırarak, anlık sesli dönütlerle süreci oyunlaştıran ve bağımsız kullanımı destekleyen bir eğitim materyali geliştirmekti. Temel okuma-yazma çağındaki görme engelli öğrenciler, aileleri ve özel eğitim kurumları projemizin ana hedef kitlesidir. Bu doğrultuda geliştirdiğimiz sistem; Arduino Uno kontrolcüsü barındıran bir ana ünite ile içine RFID etiketleri gizlenmiş, 3D yazıcıyla üretilen Braille kabartmalı küplerden oluşmaktadır. Cihazımız etkileşimli bir yapı sunarak "Öğrenme" ve "Test" olmak üzere iki farklı modda çalışır. Öğrenme modunda, ana ünitedeki üç yuvadan birine yerleştirilen küp RFID sensörlerle algılanır ve o harfin okunuşu DFPlayer ses modülü üzerinden anında seslendirilir. Test modunda ise sistem rastgele üç harfli bir kelime (örneğin "ALİ") söyler, öğrenciden bu kelimeyi küplerle dizmesini bekler ve anında doğru veya yanlış dönütü vererek aktif bir pratik imkanı sağlar. Ayrıca 3 basamaklı sayılara kadar olan sayıların okunuşlarını duyarak, doğru sayıyı yazıp yazamadığı kontrolü de bu sistemle yapılabilir. Örneğin, test aşamasında “yüz yirmi üç” sesini duyan öğrenci sırasıyla 123 rakamlarını içeren Braille küpleri yerleştirerek bilgisini test eder. Bu yönüyle temel matematik öğretimi için de fayda sağlar. Bu yaklaşımla, piyasadaki yüksek maliyetli ithal setlere kıyasla okullarda dahi kolayca üretilebilecek yerli, ekonomik ve açık kaynaklı bir alternatif ortaya koyuyoruz. Projemiz, İnsanlık Yararına Teknolojiler yarışmasının "Eğitim, Kültür ve Dijital Deneyim Teknolojileri" alt temasıyla birebir uyumludur. Dezavantajlı bireylerin eğitim süreçlerine erişilebilir, dijital ve donanım destekli bir çözüm sunmaktadır.

### 1.2. Proje Amacı ve Toplumsal Faydası

Projemizin temel amacı, görme engelli öğrencilerin okuma-yazma öğrenimindeki en büyük zorluk olan "sürekli rehber/eğitmen ihtiyacını" ortadan kaldırmaktır. Geliştirdiğimiz anlık sesli geri bildirim sistemi ve oyunlaştırılmış test modları sayesinde, öğrencilerin kendi hatalarını anında fark etmeleri, kendi hızlarında ve tamamen bağımsız bir şekilde Braille alfabesini öğrenmeleri amaçlanmaktadır. Klasik ezber yöntemlerinin aksine, bu interaktif yaklaşım çocuğun öğrenme motivasyonunu yüksek tutmayı hedefler. Toplumsal fayda bağlamında ise projemiz, eğitimde fırsat eşitliği yaratmaya odaklanmaktadır. Günümüzde etkileşimli ve dijital Braille eğitim setleri genellikle ithal edilmekte ve çok yüksek fiyatlara satılmaktadır. Dokunuş projesinin standart elektronik bileşenler (Arduino, RFID) ve 3D yazıcı teknolojisi kullanılarak açık kaynak kodlu tasarlanması, maliyetleri düşürmektedir. Bu durum; bütçesi kısıtlı devlet okullarının, özel eğitim merkezlerinin ve dar gelirli ailelerin nitelikli teknolojik eğitim materyallerine erişimini kolaylaştıracak, dezavantajlı bireylerin eğitim hayatına ve topluma entegrasyon sürecini hızlandıracaktır.

### 2. PROBLEMİN TANIMI VE ÇÖZÜM ÖNERİSİ

### 2.1. Problemin Tanımı ve Önemi

Görme engelli bireylerin eğitim hayatlarındaki en kritik aşama, temel okuma-yazma becerisi olan Braille alfabesinin öğrenilmesidir. Mevcut sistemde bu süreç, özel eğitim öğretmenlerinin veya ebeveynlerin öğrenciyle birebir ve sürekli ilgilenmesini gerektirmektedir. Öğrencinin kabartma harflere dokunurken harfi yanlış algılaması durumunda anında düzeltecek bir yetişkine ihtiyaç duyması, bağımsız öğrenme sürecini engellemekte ve çocuğun özgüven gelişimini yavaşlatmaktadır. Ayrıca, klasik kabartma kitaplarla yapılan tekrara dayalı eğitimler, erken yaştaki çocukların ilgisini çabuk kaybetmesine yol açmaktadır. Öte yandan, süreci etkileşimli hale getiren teknolojik ve elektronik Braille eğitim materyalleri piyasada mevcut olsa da, bu ürünlerin neredeyse tamamı yüksek maliyetli ve Türkçe karakter uyumu olmayan sistemlerdir. Bu durum, dar gelirli ailelerin ve kısıtlı bütçesi olan devlet okullarının bu eğitim materyallerine ulaşmasını zorlaştırmakta, eğitimde fırsat eşitsizliği sorununu derinleştirmektedir.

### 2.2. Çözüm Önerisi

Belirtilen sorunları ortadan kaldırmak için görme engelli çocukların kendi başlarına pratik yapabilmelerine olanak tanıyan "Dokunuş" eğitim setini tasarladık. Çözümümüz, 3D yazıcı ile üretilen ve içlerinde gizli RFID etiketler barındıran Braille küplerinin, 3 yuvalı ana okuyucu üniteyle etkileşime girmesi prensibine dayanır. Öğrenci bir harf küpünü cihaza yerleştirdiğinde, sistem DFPlayer modülü aracılığıyla anında sesli geri bildirim vererek harfi öğretir ve eğitmen bağımlılığını ortadan kaldırır. Klasik ezber yöntemlerinin aksine cihazımızda yer alan "Test Modu", çocuğa rastgele 3 harfli kelimeleri hatta 3 basamağa kadar sayıları sorup doğru dizilimi bekleyerek eğitimi oyunlaştırır. Çalışma mantığı şekildeki gibidir. (Bkz. 1). Hata yapıldığında verilen sesli yönlendirmeler sayesinde çocuk, kendi kendini düzelterek aktif öğrenme sürecine dahil olur. Çözümümüz, pahalı sensörler yerine basit elektronik devre elemanları ve 3D baskı teknolojisi kullandığı için düşük maliyetlidir. Bu sayede okullarda yerel olarak üretilebilir bir yapı sunarak eğitim materyallerine erişimi kolaylaştırmaktadır.

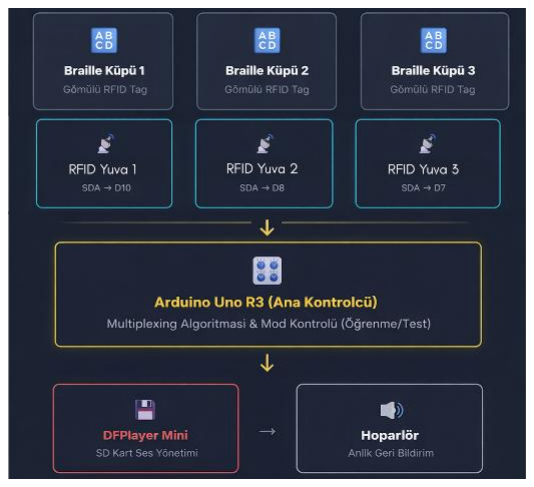
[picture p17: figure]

Şekil 1: Dokunuş Projesi şematik gösterimi

Son akademik veriler de dokunma ve işitme duyularına eşzamanlı hitap eden akıllı Braille sistemlerinin, çocuklarda öğrenme hızını ve eğitim kalitesini ciddi oranda artırdığını ortaya koymaktadır (Kintonova vd., 2025).

### 3. ÖZGÜNLÜK, UYGULANABİLİRLİK VE

SÜRDÜRÜLEBİLİRLİK

### 3.1. Özgünlük

Görme engellilerin eğitimi üzerine literatür ve geçmiş proje raporları incelendiğinde, çeşitli dijital çalışmalar yapıldığı görülmektedir. Örneğin geçmiş yıllarda, Braille öğretimini kolaylaştırmak için dijital çözümler üzerine odaklanmak gerektiği (2019, İnsanlık Yararına Teknolojiler Yarışması, Eğitim Kategorisi, Hexabros Takımı) tespitiyle yola çıkılan farklı ve değerli donanım/yazılım projeleri geliştirilmiştir. Piyasada ve literatürde genellikle metni kabartmaya çeviren pahalı "elektronik yenilenebilir Braille ekranlar" (solenoid motorlu) veya görseli sese çeviren yapay zeka tabanlı yazılımlar öne çıkmaktadır. Dokunuş projesinin özgün ve ayırıcı tarafı ise "fiziksel dokunma hissini dijital etkileşimle birleştiren, hareketli mekanik parça içermeyen bağımsız bir öğretmen" modeli sunmasıdır. Piyasada ahşap veya plastik Braille küpleri (Örn: Lego Braille Bricks) bulunsa da bunlar dijital dönüt veremez, mutlaka gören birinin rehberliğini gerektirir. Bizim sistemimiz, RFID teknolojisini kullanarak donanımsal sadelikle akıllı etkileşimi harmanlar. Özellikle cihazın kelime sorup kullanıcının doğru küpleri dizmesini beklediği "Test Modu", ezberci metodu aşıp, maarif modelin de tavsiye ettiği öğrenci merkezli, interaktif bir oyunlaştırılmış öğrenme modeli ortaya koymaktadır.

### 3.2. Uygulanabilirlik ve Sürdürülebilirlik

Projemizin donanım mimarisi, piyasada kolaylıkla bulunabilen ve endüstri standardı haline gelmiş mikrodenetleyici (Arduino Uno) ve modüller (MFRC522, DFPlayer) üzerine inşa edilmiştir. Kompleks mekanik motorlar kullanılmadığı için sistemin bozulma riski minimumdur ve sahada (okullarda) uygulanabilirliği yüksektir. Projemizin ana iskeleti ve küpleri, çevre dostu PLA/PETG filamentler kullanılarak 3D yazıcılarla üretilecek şekilde tasarlanmıştır. Bu durum, yedek parça sorununun önüne geçer; kaybolan veya kırılan bir harf küpü okulun kendi 3D yazıcısında saatler içinde yeniden üretilebilir ve içine basit bir RFID etiket yapıştırılarak sisteme tanıtılabilir. Geliştirdiğimiz yazılımın ve 3D tasarımların açık kaynaklı olarak paylaşılacak olması, projenin sadece takımımız tarafından değil, Türkiye'deki tüm özel eğitim kurumları ve Maker atölyeleri tarafından kolayca kopyalanıp çoğaltılabilmesini, böylelikle uzun yıllar sürdürülebilir bir fayda yaratmasını sağlayacaktır. Test aşamasında kullanılan sesli metinler kolaylıkla güncellenebilir ve Türkçe dışında diller için de kullanılabilir. Ayrıca sayı basamaklarının öğretilmesinde de kullanılabilir.

### 4. PROJENİN HAZIRLANIŞ SÜRECİ VE ÇALIŞMA YÖNTEMİ

Projemizin hazırlık sürecinde, görme engellilerin yaşadığı zorluklar üzerine yoğunlaştık. İlk aşamada, görme engelli çocukların Braille alfabesi öğrenirken yaşadığı sorunları ve piyasadaki eğitim materyallerinin neden yetersiz veya pahalı olduğunu araştırdık. Araştırma sonuçlarına göre, kendi bağımsız çözümümüzü geliştirmek için gerekli donanım ve yazılımı belirledik. Çözmek zorunda kaldığımız kritik teknik sorun, 3 adet RFID sensörünün yan yana geldiğinde manyetik alanlarının birbirini etkilemesi ve hatalı okuma yapmasıydı (çakışma). Bu sorunu donanımsal izolasyonun yanı sıra, yazılım tarafında sensörleri aynı anda değil sırayla okuyan bir çoğullama (multiplexing) algoritması geliştirerek çözmeyi başardık. Sürecin planlandığı gibi ilerlemesi ve projenin tamamlanması için yeteneklerimize göre şu görev dağılımını yaptık: Takım Kaptanı daha çok yazılım aşamasında görev aldı. Literatür taraması yaptı. Projenin yazılım mimarisinden sorumlu oldu. Arduino kodlarını yazarak, RFID sensörlerin SPI haberleşmesindeki çakışmalarını engelledi ve DFPlayer ses modülünün SD karttaki doğru ses dosyalarını çalmasını sağladı. Ayrıca TEKNOFEST proje raporlarının resmi şablonlara uygun olarak hazırlanması görevini üstlendi. Takım Üyesi donanım ve 3D tasarım işlerini üstlendi. Okullarda Braille öğretiminde kullanılan eğitim setlerini araştırdı. Elektronik devre kurulumundan ve mekanik tasarımdan sorumlu oldu. Arduino Uno ile devreyi kurdu. Ayrıca ana ünitenin ve içine RFID etiketleri gizlenecek olan Braille kabartmalı harf küplerinin 3D modellemesini yaptı. Yazıcıdan 3D baskı aldı. Danışman öğretmen projenin zaman çizelgesini yönetti, teknik konularda ve özellikle rapor yazımı sürecinde bize rehberlik etti. Her aşamada denetim sağlayarak sürecin takvime uygun ilerlemesini sağladı.

### 5. PROJE TAKIMI

Sıra | Takımdaki Görevi | Eğitim Seviyesi | Projedeki Rolü | Sınıf | Üye Rolü
– | Danışman | – | Zaman Yönetimi ,Proje Takibi, Rehberlik | – | Rehber
1 | Takım Lideri | Lise | Yazılım , Literatür Taraması, Rapor Yazımı | 11 | Öğrenci
2 | Üye | Lise | 3D Modelleme, Devre Kurulumu | 11 | Öğrenci

### 6. KAYNAKLAR

Hexabros Takımı. (2019). İnsanlık Yararına Teknolojiler Yarışması, Eğitim Kategorisi Proje Raporu. TEKNOFEST Geçmiş Yıllar Rapor Arşivi.

MEB Özel Eğitim ve Rehberlik Hizmetleri Genel Müdürlüğü. (2024). Görme Engelli Bireyler İçin Braille Okuma Yazma Öğretimi Kılavuzu.

Kintonova, A., Gabdreshov, G., Yensebaev, T., Sadykova, R., Yensebayev, N., Kulbasov, S., & Magzymov, D. (2025). Experiment on teaching visually impaired and blind children using a mobile electronic alphabetic braille trainer. AI & SOCIETY, 40(2), 1059–1074. https://doi.org/10.1007/s00146-024-01883-6

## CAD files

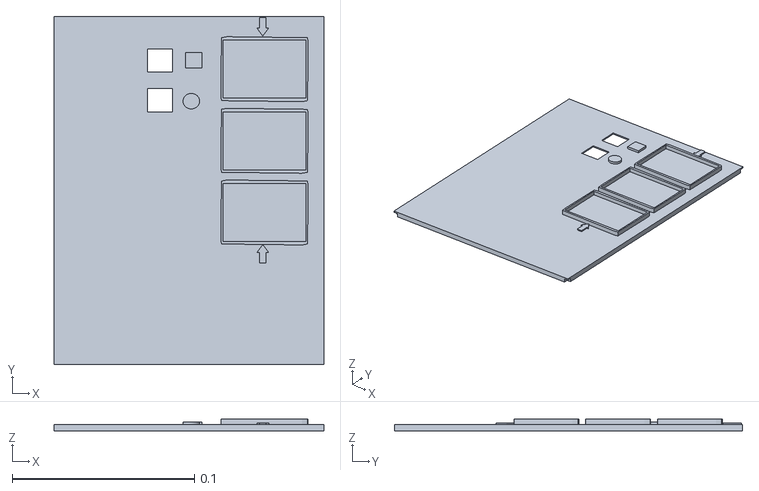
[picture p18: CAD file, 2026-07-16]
stl/ust-kapak.stl
0.148 x 0.191 x 0.0065

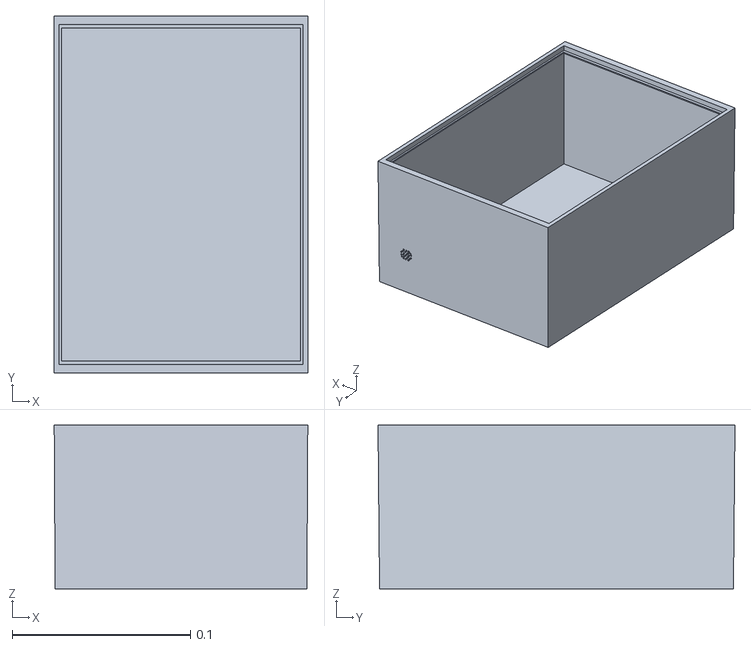
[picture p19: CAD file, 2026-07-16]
stl/alt-kutu.stl
0.142 x 0.2 x 0.0918

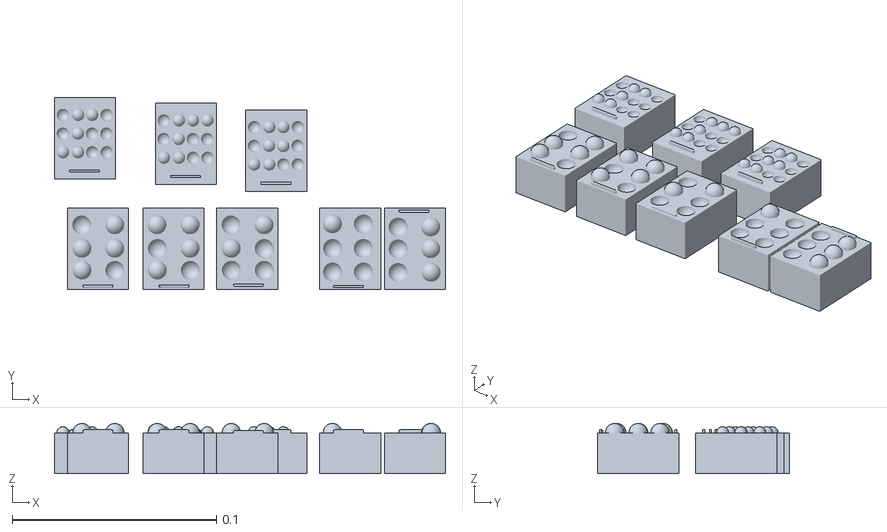
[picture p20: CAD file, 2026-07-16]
stl/kupler.stl
0.192 x 0.094 x 0.0246

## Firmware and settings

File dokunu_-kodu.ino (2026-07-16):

#include <SPI.h>
#include <MFRC522.h>
#include <SoftwareSerial.h>
#include <DFRobotDFPlayerMini.h>

#define SS1 10
#define SS2 7
#define SS3 6
#define RST 9
#define BTN_MOD A0   // Mod değiştirme butonu
#define BTN_ONAY A1  // Onaylama butonu

// ========================================================
// SES DOSYASI NUMARALARI VE SÜRE AYARLARI
// ========================================================
int sistemBasladiSesi = 0; // Açılış sesi (0004.mp3)
int mod1Sesi = 13;          // Eğitim Modu sesi (0013.mp3)
int mod2Sesi = 14;          // Hece Modu sesi (0014.mp3)
int mod3Sesi = 15;          // Sayı Modu sesi (0015.mp3)

int dogruCevapSesi = 11;    // Doğru cevap sesi (0011.mp3)
int yanlisCevapSesi = 12;   // Yanlış cevap sesi (0012.mp3)

// SÜRELER (Milisaniye cinsinden. 1000 ms = 1 Saniye)
unsigned long acilisSesiSuresi = 5000;  // Sistem başladı sesinin süresi (5 saniye)
unsigned long modGecisSuresi = 2500;    // Mod anons sesinin süresi (2.5 saniye)
unsigned long dogruYanlisSuresi = 3000; // Doğru/Yanlış sesinin süresi (3 saniye)
// ========================================================

MFRC522 rfid1(SS1, RST);
MFRC522 rfid2(SS2, RST);
MFRC522 rfid3(SS3, RST);

SoftwareSerial mySerial(5, 4); // RX, TX
DFRobotDFPlayerMini dfplayer;

// Yuvalardan okunan anlık harfler/rakamlar
String yuva1 = "", yuva2 = "", yuva3 = "";
int sira = 1; // 1: 1. Yuva, 2: 2. Yuva, 3: 3. Yuva, 4: Buton Bekleme aşaması

int guncelMod = 1; 
bool yeniSoruSor = true;
String beklenenCevap = "";

// HATA VEREN DEĞİŞKEN BURAYA EKLENDİ (Eğitim modunun kararlı çalışması için)
char sonOkunanKup = '?'; 

bool lastModButtonState = HIGH;
bool lastOnayButtonState = HIGH;
unsigned long sonModZamani = 0;
const int debounceGecikmesi = 200; // Mod butonu parazit engelleme süresi

struct KartBilgisi {
  byte uid[4];
  String harf;
  int sesDosyasi;
};

KartBilgisi kartlar[] = {
  {{0xFF, 0x0F, 0xC3, 0x19}, "A", 1},
  {{0xFF, 0x0F, 0x54, 0x21}, "E", 2},
  {{0xFF, 0x0F, 0x55, 0x21}, "I", 3},
  {{0xFF, 0x0F, 0x67, 0x18}, "N", 4},
  {{0xFF, 0x0F, 0xD3, 0xFD}, "L", 5},
  {{0xFF, 0x0F, 0xD4, 0xFD}, "T", 6},
  {{0xFF, 0x0F, 0xD6, 0xFD}, "3", 7},
  {{0xFF, 0x0F, 0xD5, 0xFD}, "2", 8},
  {{0xFF, 0x0F, 0xC2, 0x19}, "1", 9}
};

String heceSorular[] = {"TEL", "EL", "AT", "NIL", "TAN", "IN", "ALI"};
int heceSesleri[] = {17, 18, 19, 20, 21, 22, 23};
String sayiSorular[] = {"12", "32", "123", "213", "23"};
int sayiSesleri[] = {24, 25, 26, 27, 28};

void setup() {
  Serial.begin(9600);
  while (!Serial) { ; } 
  
  Serial.println("Sistem baslatiliyor...");

  mySerial.begin(9600);
  SPI.begin();

  pinMode(SS1, OUTPUT); digitalWrite(SS1, HIGH);
  pinMode(SS2, OUTPUT); digitalWrite(SS2, HIGH);
  pinMode(SS3, OUTPUT); digitalWrite(SS3, HIGH);
  
  pinMode(BTN_MOD, INPUT_PULLUP);
  pinMode(BTN_ONAY, INPUT_PULLUP);

  rfid1.PCD_Init(); rfid2.PCD_Init(); rfid3.PCD_Init();
  
  if (!dfplayer.begin(mySerial)) {
    Serial.println("DFPlayer baglantisi kurulamadi! Kablolari kontrol et.");
  } else {
    Serial.println("DFPlayer basarili.");
    dfplayer.volume(25);
    
    // Sistem Açılış Akışı
    dfplayer.playMp3Folder(sistemBasladiSesi);
    delay(acilisSesiSuresi); 
    
    dfplayer.playMp3Folder(mod1Sesi);
    delay(modGecisSuresi);  
  }
  
  Serial.println("Mod 1: Egitim Modu Aktif. 1. Yuvaya kart koyun.");
}

void loop() {
  // 1) MOD BUTONU KONTROLÜ (Eğitim / Hece / Sayı Seçimi)
  bool currentModButton = digitalRead(BTN_MOD);
  if (lastModButtonState == HIGH && currentModButton == LOW) {
    if ((millis() - sonModZamani) > debounceGecikmesi) {
      guncelMod++;
      if (guncelMod > 3) guncelMod = 1;
      
      Serial.print("Mod degisti: "); Serial.println(guncelMod);
      
      // Yeni modun başlangıç sesini çal
      if (guncelMod == 1)      dfplayer.playMp3Folder(mod1Sesi);
      else if (guncelMod == 2) dfplayer.playMp3Folder(mod2Sesi);
      else if (guncelMod == 3) dfplayer.playMp3Folder(mod3Sesi);
      
      delay(modGecisSuresi); // Mod sesinin bitmesini beklet
      
      // Durumu sıfırla
      sira = 1; yuva1 = ""; yuva2 = ""; yuva3 = "";
      yeniSoruSor = true;
      sonModZamani = millis();
    }
  }
  lastModButtonState = currentModButton;

  // 2) SEÇİLİ MODA GÖRE ÇALIŞMA AKIŞI
  if (guncelMod == 1) {
    // MOD 1: EĞİTİM (Kart okundukça harf sesi çıkarır, buton kontrolü yoktur)
    char k = rfidEgitimOku(rfid1, SS1);
    if (k == '?') k = rfidEgitimOku(rfid2, SS2);
    if (k == '?') k = rfidEgitimOku(rfid3, SS3);
    
    // Eğitim modunda okunan harf sesini doğrudan çalar
    if (k != '?' && k != sonOkunanKup) {
      Serial.print("Egitim Okunan: "); Serial.println(k);
      for(int i = 0; i < 9; i++) {
        if(kartlar[i].harf[0] == k) {
          dfplayer.playMp3Folder(kartlar[i].sesDosyasi);
        }
      }
      sonOkunanKup = k;
      delay(1000);
    } else if(k == '?') {
      sonOkunanKup = '?';
    }
  } 
  else {
    // MOD 2 & MOD 3: TEST MODLARI (Sırayla okuma yapar, Butonla onaylanır)
    
    if (yeniSoruSor) {
      delay(500); 
      int r = (guncelMod == 2) ? random(0, 7) : random(0, 5);
      beklenenCevap = (guncelMod == 2) ? heceSorular[r] : sayiSorular[r];
      
      Serial.print("Soru Soruldu: "); Serial.println(beklenenCevap);
      dfplayer.playMp3Folder((guncelMod == 2) ? heceSesleri[r] : sayiSesleri[r]);
      
      yeniSoruSor = false;
      sira = 1; yuva1 = ""; yuva2 = ""; yuva3 = "";
      Serial.println("Sıralı okuma basladi. 1. yuvaya kartı koyun.");
    }

    // Çalışan sıralı kart okuma adımları
    if (sira == 1) {
      if (yuva1 == "") yuva1 = kartOku(rfid1, SS1, 1);
    } 
    else if (sira == 2) {
      if (yuva2 == "") yuva2 = kartOku(rfid2, SS2, 2);
    } 
    else if (sira == 3) {
      if (yuva3 == "") yuva3 = kartOku(rfid3, SS3, 3);
    }

    // Onaylama Butonuna Basıldığında Cevabı Kontrol Et
    bool currentOnayButton = digitalRead(BTN_ONAY);
    if (lastOnayButtonState == HIGH && currentOnayButton == LOW) {
      
      String cevap = yuva1 + yuva2 + yuva3;
      Serial.print("Kontrol ediliyor... Verilen Cevap: "); Serial.println(cevap);
      
      if (cevap == beklenenCevap) {
        Serial.println("Sonuc: DOGRU!");
        dfplayer.playMp3Folder(dogruCevapSesi);
        delay(dogruYanlisSuresi); 
        yeniSoruSor = true;       
      } else {
        Serial.println("Sonuc: YANLIS! Tekrar deneyin.");
        dfplayer.playMp3Folder(yanlisCevapSesi);
        delay(dogruYanlisSuresi); 
        
        sira = 1; yuva1 = ""; yuva2 = ""; yuva3 = "";
        Serial.println("Yuvalar temizlendi. 1. yuvadan baslayarak tekrar dizin.");
      }
    }
    lastOnayButtonState = currentOnayButton;
  }
}

// SIRALI OKUMA FONKSİYONU
String kartOku(MFRC522 &rfid, int pin, int yuvaNo) {
  digitalWrite(pin, LOW);
  String bulunanHarf = "";
  if (rfid.PICC_IsNewCardPresent() && rfid.PICC_ReadCardSerial()) {
    for (int i = 0; i < 9; i++) {
      if (memcmp(rfid.uid.uidByte, kartlar[i].uid, 4) == 0) {
        bulunanHarf = kartlar[i].harf;
        Serial.print("Yuva "); Serial.print(yuvaNo); 
        Serial.println(" okundu: " + bulunanHarf);
        dfplayer.playMp3Folder(kartlar[i].sesDosyasi);
        if (sira < 4) sira++; 
        break;
      }
    }
    rfid.PICC_HaltA();
  }
  digitalWrite(pin, HIGH);
  return bulunanHarf;
}

// Eğitim Modu için serbest okuma yapan yardımcı fonksiyon
char rfidEgitimOku(MFRC522 &rfid, int ssPin) {
  digitalWrite(SS1, HIGH); digitalWrite(SS2, HIGH); digitalWrite(SS3, HIGH);
  digitalWrite(ssPin, LOW);
  char sonuc = '?';
  if (rfid.PICC_IsNewCardPresent() && rfid.PICC_ReadCardSerial()) {
    for (int i = 0; i < 9; i++) {
      if (memcmp(rfid.uid.uidByte, kartlar[i].uid, 4) == 0) { 
        sonuc = kartlar[i].harf[0]; 
        break; 
      }
    }
    rfid.PICC_HaltA(); 
  }
  digitalWrite(ssPin, HIGH);
  return sonuc;
}
